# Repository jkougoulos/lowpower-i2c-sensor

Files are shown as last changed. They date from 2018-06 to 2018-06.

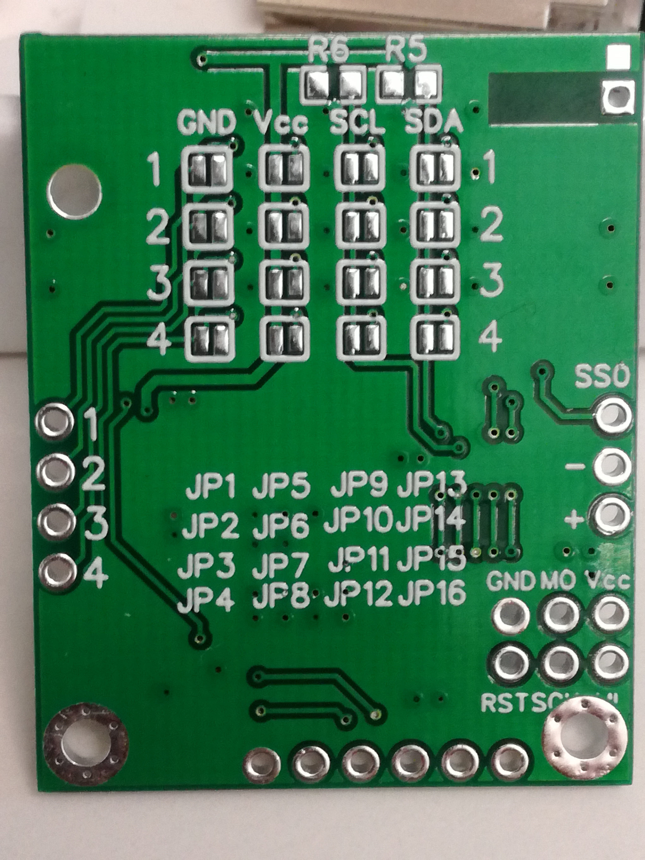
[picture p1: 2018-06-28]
Gerber_LowPowerI2CWirelessSensor-1.0-PCB/IMG_20180601_175646.jpg

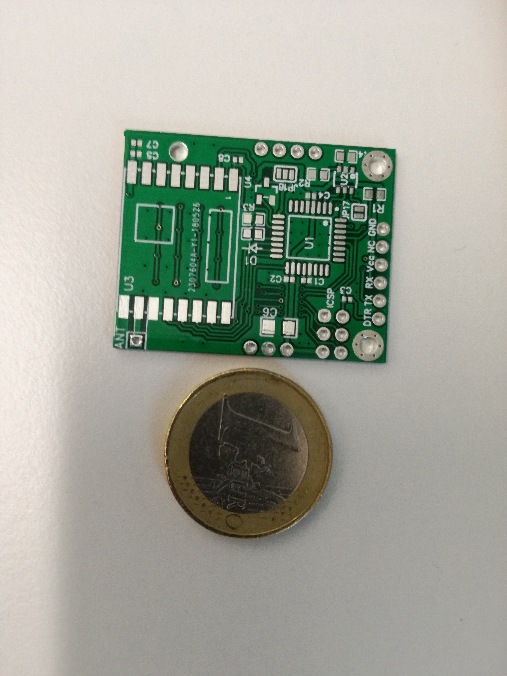
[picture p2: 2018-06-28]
Gerber_LowPowerI2CWirelessSensor-1.0-PCB/IMG_20180601_144345.jpg

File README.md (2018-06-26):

# lowpower-i2c-sensor
Another ATMega328PB based wireless sensor, designed for low power consumption

Currently testing and optimizing for 1Mhz operation, in order to be in Safe operating voltage without activating BOD (Vcc >= 1.8V). (4Mhz is not an option yet, no external oscillator forseen in design, so possible options are 1 or 8 Mhz)

using TPL5010 for low power consumption during sleep
Delay between wake-ups is governed by R2 & R4. Default { R2 = 29.4KOhm, R4 = not soldered } == 120.5-121 sec. 29.35KOhm is calculated for 2 min per datasheet (check it for possible values and combinations)

STM1061N for low battery voltage detection. 
Currently testing with 1.9v threshold (STM1061N19WX6F)
On the software side detection occurs using a pin CHANGE interrupt, in order to detect low voltage during the whole operation of the sensor (except sleep mode)

RFM69W for wireless communication, 45mA @ +13dBm. 

Jumper exists on the front side (JP18) for selecting power source for STM1061 (Vcc or PIN). Pin seems to work, next revision probably will not have the jumper.

JP19 enables the watchdog reset functionality of TPL5010. This will be probably removed in future version, since TPL5010 expects an initial pulse to be activated. However, if it is not activated, R2 seems to stay in measuring mode (further testing required), wasting battery capacity.

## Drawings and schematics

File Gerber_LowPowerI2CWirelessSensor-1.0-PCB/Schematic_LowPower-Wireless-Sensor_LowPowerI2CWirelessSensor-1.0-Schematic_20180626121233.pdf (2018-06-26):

# PE0(PTCXY/SDA1/ICP4/ACO) 3 VCC 4 GND 5

## VCC

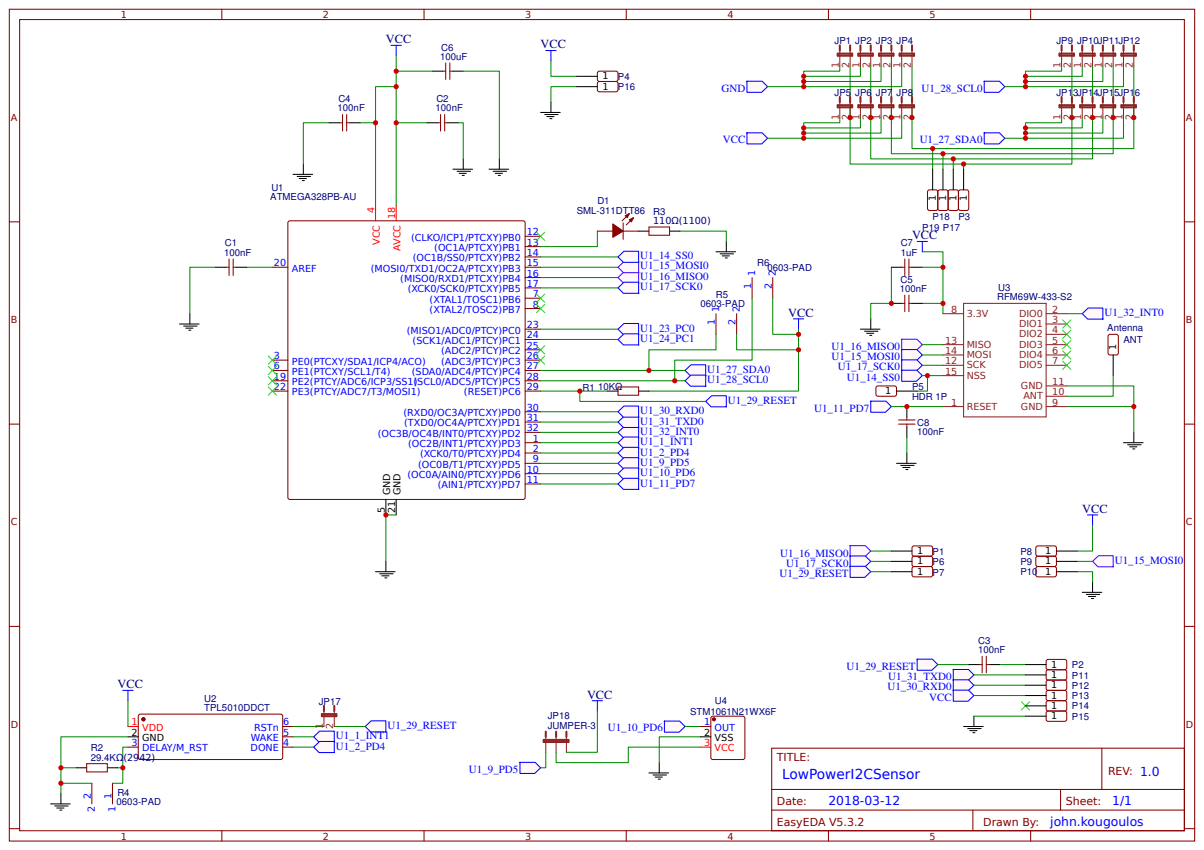
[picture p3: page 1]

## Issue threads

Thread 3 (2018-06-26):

Add extra pins for external devices

jkougoulos, 2018-06-26:
A few more pins would be nice to have, eg:
- something to receive interrupts / handle buttons
- have a pin to pulse and view the various phases in an oscilloscope

jkougoulos, 2018-06-26:
Don't forget to check requirements for PTC style buttons

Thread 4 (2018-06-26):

add a manual RESET switch - improve RESET mechanism

jkougoulos, 2018-06-26:
A switch for issuing RESET manually would be useful.
Need to check AVR042, but in general reset will probably get handled by TPL5010 manual reset options
Consider switching the RST pullup to 100KOhm, but need to check compaitibility with Serial upload (it should be ok), and ATMEL/Microchip debuggers.
Consider if bypass capacitor is required as per AVR042, ESD protection diodes, resistor. Normally these are not needed since ESD is actually something that would be handled by TPL5010 but detailed RTFM required.
Need to check if capacitor between DTR & RST for uploading over Serial (Arduino trick) interferes with ATMEL-ICE operation https://youtu.be/EsEl9wDz_Y8?t=1076

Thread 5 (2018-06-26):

Don't block while waiting for TX

jkougoulos, 2018-06-26:
As is, MCU will wait for the TX packet to be sent in order to continue operations. Perhaps do something else in the mean time (3-4ms)... but all calculation are already done :(

jkougoulos, 2018-06-27:
maybe go to sleep and wait for TX_done interrupt or low voltage to wake-up? but we need to make sure that we received TX_done to go further, so that in low-voltage we don't turn on the led while transmitting

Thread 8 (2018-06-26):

Consider alternatives for STM1061N

jkougoulos, 2018-06-26:
STM1061N might be difficult to find for specific voltages.
Consider alteratives. eg APX803L (Diodes incorporated), MCP111 (Microchip), check: https://www.digikey.de/products/en/integrated-circuits-ics/pmic-supervisors/691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

jkougoulos, 2021-07-08:
xc6135 super low power

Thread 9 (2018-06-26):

Self discharge of C6

jkougoulos, 2018-06-26:
Most of  battery power is consumed by self-discharge of C6 during idle time.
Need to measure somehow if the calculations are correct on the amount of battery capacity we lose and consider if the capacitor plays an important role on helping the battery for the high consuming pulse during TX. Perhaps using a 1-10uF X7R just for bypass would work better (and cost less)

jkougoulos, 2018-06-26:
See also:
https://www.embedded.com/electronics-blogs/break-points/4430050/Using-a-capacitor-to-sustain-battery-life

http://www.ti.com/lit/wp/swra349/swra349.pdf (Coin cells and peak current draw
By Mathias Jensen)

https://m.eet.com/media/1121454/c0924post.pdf

http://data.energizer.com/pdfs/lithiumcoin_appman.pdf

https://electronics.stackexchange.com/questions/43306/pulse-powering-heavy-loads-with-a-coin-cell

https://www.embedded.com/electronics-blogs/break-points/4429960/How-much-energy-can-you-really-get-from-a-coin-cell-

https://www.embedded.com/electronics-blogs/break-points/4418098/A-sneak-preview

jkougoulos, 2018-06-30:
testing required to see if large C6 actually helps. Actually it is 100uF but at 3v probably the usable is ~50uF. In any case, at 45mA of RFM69W full power, we need significantly bigger capacitor. The question though is if it helps mitigating the effects of increased IR of the battery (coin cell) at eg half life etc.
Test proposed:
fast cycles (8-16s) with 100uF (measure days until low bat & end of service)
fast cycles (8-16s) with 10uF
slower cycles (eg 64s) and check if the performance is linear, according to calculations.
Always start with same battery type, (cheap CR2032), similar environmental conditions (indoor).

at 14s delay, calculations predict at 180mAh ~448 days of operations. hmmm, that seems to long for a coin cell transmitting every 14s @45mA

jkougoulos, 2018-07-03:
http://cache.freescale.com/files/rf_if/doc/app_note/AN4573.pdf

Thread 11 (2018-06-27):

utilize hardware watchdog for unexpected bugs

jkougoulos, 2018-06-27:
We have to trigger watchdog intervention when something unexpected happens / fail (relatively) fast / heisenbugs etc
- packet was not sent
- temperature/humidity/pressure reading are out of the minimum/maximum
- make sure to send reset to RFM when starting up, ensuring that the module resets if something goes wrong

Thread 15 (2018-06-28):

Placeholder for various perfomance metrics

jkougoulos, 2018-06-28:
44-45ms runtime per cycle as of now:
Sequence:
- 13.5ms for taking measurement
- 13-14ms calculations/compensation & I2C retrieval (Adafruit library with enhancements for faster I2C)
- 5ms ? msg preparation (itoa/ltoa based, sprintf was ~10ms)
- 4-5 ms SPI I/O
- 4-5 ms wreless transmit
- 1ms LED on

Cheap multimeter measurements
- 640uA CPU when active (but idle / in delay()

Idle current cannot be measured by this cheap thing, getting 0uA (perhaps we are under 1uA)

Tested Bosch library (measure & calculate), without any optimization .
see: https://github.com/jkougoulos/BME280_driver/blob/master/BME280sensor.ino
Perhaps need to test using atmel studio, or disassembly.
- 30ms Float mode (strange result, need to check why float is faster!)
- ~39 ms int32/int64

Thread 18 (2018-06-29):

Provide visual feedback for low battery status

jkougoulos, 2018-06-29:

jkougoulos, 2018-06-29:
quick flashing 2 times is not visible without heavily delaying process time.

Perhaps in next hw version include a second led? What color though, so that it works with 2v?

Closed 2018-06-30.

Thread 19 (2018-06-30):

When TPL5010 is configured for small delays, cannot upload sketch over serial

jkougoulos, 2018-06-30:
noticed on test device 2, (tpl5010 configured with 29.4K // 22K -> 12583.66 Ohm) that the device resets frequently, making sketch upload impossible (at 9600bps).
Need to verify if TPL5010 issues reset (not expected)

jkougoulos, 2018-06-30:
perhaps disconnect JP19 to verify if TPL5010 brings RST low

jkougoulos, 2018-06-30:
could not reproduce

jkougoulos, 2018-07-16:
issue is still there, TPL5010 seems to send watchdog reset (not verified though) at 2x period. Perhaps during reset a pulse is given to done pin?

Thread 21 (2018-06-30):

Long term test 01 (TSTKO-0002)

jkougoulos, 2018-06-30:
Starting today 30.06.2018 long term test:
HW characteristics:
R2 // R4 == 29.4K // 22K
R1 = 100K (had done this to debug bootloader issues)

Battery επιπλάδικου:
CR2032 / 3.34v open voltage on multimeter

jkougoulos, 2018-07-05:
05.07.2018 watchdog reset followed by many reboots observed, then back to normal:
2018-07-05 15:35:52 2018-07-05 15:35:52 /dev/ttyUSB0 Received Frame is:bytearray(b'#SENSDATA#ID1:3e7/MS0:b180/C00:6ff3/T01:10a/H01:1c4/P01:275a/BAT:OK/RS0:-29')
2018-07-05 15:36:06 2018-07-05 15:36:06 /dev/ttyUSB0 Received Frame is:bytearray(b'#SENSDATA#ID1:3e7/MS0:b040/C00:6ff4/T01:10a/H01:1c6/P01:275b/BAT:OK/RS0:-33')
2018-07-05 15:36:21 2018-07-05 15:36:21 /dev/ttyUSB0 Received Frame is:bytearray(b'#SENSDATA#ID1:3e7/MS0:b100/C00:6ff5/T01:10a/H01:1c2/P01:275a/BAT:OK/RS0:-32')
2018-07-05 15:36:35 2018-07-05 15:36:35 /dev/ttyUSB0 Received Frame is:bytearray(b'#SENSDATA#ID1:3e7/MS0:b100/C00:6ff6/T01:10a/H01:1c3/P01:275a/BAT:OK/RS0:-33')
2018-07-05 15:36:50 2018-07-05 15:36:50 /dev/ttyUSB0 Received Frame is:bytearray(b'#SENSDATA#ID1:3e7/MS0:b040/C00:6ff7/T01:10a/H01:1c5/P01:275a/BAT:OK/RS0:-33')
2018-07-05 15:37:07 2018-07-05 15:37:07 /dev/ttyUSB0 Received Frame is:bytearray(b'#SENSDATA#ID1:3e7/MS0:1162c0/C00:1/T01:10a/H01:1c1/P01:275a/BAT:OK/RS0:-29')
2018-07-05 15:37:15 2018-07-05 15:37:15 /dev/ttyUSB0 Received Frame is:bytearray(b'#SENSDATA#ID1:3e7/MS0:1162c0/C00:1/T01:10a/H01:1c1/P01:2759/BAT:OK/RS0:-33')
2018-07-05 15:37:20 2018-07-05 15:37:20 /dev/ttyUSB0 Received Frame is:bytearray(b'#SENSDATA#ID1:3e7/MS0:1162c0/C00:1/T01:10a/H01:1c5/P01:275a/BAT:OK/RS0:-33')
2018-07-05 15:37:20 2018-07-05 15:37:20 /dev/ttyUSB0 Received Frame is:bytearray(b'#SENSDATA#ID1:3e7/MS0:ae00/C00:2/T01:10a/H01:1c5/P01:275a/BAT:OK/RS0:-33')
2018-07-05 15:37:28 2018-07-05 15:37:28 /dev/ttyUSB0 Received Frame is:bytearray(b'#SENSDATA#ID1:3e7/MS0:1162c0/C00:1/T01:10a/H01:1c6/P01:2759/BAT:OK/RS0:-29')
2018-07-05 15:37:33 2018-07-05 15:37:33 /dev/ttyUSB0 Received Frame is:bytearray(b'#SENSDATA#ID1:3e7/MS0:af00/C00:2/T01:10a/H01:1c7/P01:275a/BAT:OK/RS0:-33')
2018-07-05 15:37:40 2018-07-05 15:37:40 /dev/ttyUSB0 Received Frame is:bytearray(b'#SENSDATA#ID1:3e7/MS0:116280/C00:1/T01:10a/H01:1c5/P01:275a/BAT:OK/RS0:-33')
2018-07-05 15:37:46 2018-07-05 15:37:46 /dev/ttyUSB0 Received Frame is:bytearray(b'#SENSDATA#ID1:3e7/MS0:1162c0/C00:1/T01:10a/H01:1c4/P01:275a/BAT:OK/RS0:-33')
2018-07-05 15:37:48 2018-07-05 15:37:48 /dev/ttyUSB0 Received Frame is:bytearray(b'#SENSDATA#ID1:3e7/MS0:af00/C00:2/T01:10a/H01:1c5/P01:275a/BAT:OK/RS0:-33')
2018-07-05 15:38:05 2018-07-05 15:38:05 /dev/ttyUSB0 Received Frame is:bytearray(b'#SENSDATA#ID1:3e7/MS0:1164c0/C00:1/T01:10b/H01:1c4/P01:275a/BAT:OK/RS0:-29')
2018-07-05 15:38:17 2018-07-05 15:38:17 /dev/ttyUSB0 Received Frame is:bytearray(b'#SENSDATA#ID1:3e7/MS0:af00/C00:2/T01:10b/H01:1c6/P01:275a/BAT:OK/RS0:-32')
2018-07-05 15:38:31 2018-07-05 15:38:31 /dev/ttyUSB0 Received Frame is:bytearray(b'#SENSDATA#ID1:3e7/MS0:ab00/C00:3/T01:10a/H01:1c5/P01:275a/BAT:OK/RS0:-33')
2018-07-05 15:38:49 2018-07-05 15:38:49 /dev/ttyUSB0 Received Frame is:bytearray(b'#SENSDATA#ID1:3e7/MS0:116280/C00:1/T01:10a/H01:1c8/P01:275a/BAT:OK/RS0:-33')
2018-07-05 15:38:54 2018-07-05 15:38:54 /dev/ttyUSB0 Received Frame is:bytearray(b'#SENSDATA#ID1:3e7/MS0:1162c0/C00:1/T01:10a/H01:1c8/P01:275a/BAT:OK/RS0:-33')
2018-07-05 15:38:57 2018-07-05 15:38:57 /dev/ttyUSB0 Received Frame is:bytearray(b'#SENSDATA#ID1:3e7/MS0:116280/C00:1/T01:10b/H01:1c4/P01:275a/BAT:OK/RS0:-32')
2018-07-05 15:39:00 2018-07-05 15:39:00 /dev/ttyUSB0 Received Frame is:bytearray(b'#SENSDATA#ID1:3e7/MS0:aec0/C00:2/T01:10a/H01:1c4/P01:275a/BAT:OK/RS0:-33')
2018-07-05 15:39:15 2018-07-05 15:39:15 /dev/ttyUSB0 Received Frame is:bytearray(b'#SENSDATA#ID1:3e7/MS0:aa40/C00:3/T01:10a/H01:1c3/P01:275a/BAT:OK/RS0:-29')
2018-07-05 15:39:29 2018-07-05 15:39:29 /dev/ttyUSB0 Received Frame is:bytearray(b'#SENSDATA#ID1:3e7/MS0:ac00/C00:4/T01:10a/H01:1c4/P01:275a/BAT:OK/RS0:-33')
2018-07-05 15:39:44 2018-07-05 15:39:44 /dev/ttyUSB0 Received Frame is:bytearray(b'#SENSDATA#ID1:3e7/MS0:ab40/C00:5/T01:10a/H01:1c6/P01:275a/BAT:OK/RS0:-29')
2018-07-05 15:39:58 2018-07-05 15:39:58 /dev/ttyUSB0 Received Frame is:bytearray(b'#SENSDATA#ID1:3e7/MS0:aac0/C00:6/T01:10b/H01:1c2/P01:275a/BAT:OK/RS0:-33')
2018-07-05 15:40:13 2018-07-05 15:40:13 /dev/ttyUSB0 Received Frame is:bytearray(b'#SENSDATA#ID1:3e7/MS0:ab80/C00:7/T01:10b/H01:1c7/P01:275a/BAT:OK/RS0:-29')
2018-07-05 15:40:27 2018-07-05 15:40:27 /dev/ttyUSB0 Received Frame is:bytearray(b'#SENSDATA#ID1:3e7/MS0:ab00/C00:8/T01:10b/H01:1c4/P01:275a/BAT:OK/RS0:-33')
2018-07-05 15:40:42 2018-07-05 15:40:42 /dev/ttyUSB0 Received Frame is:bytearray(b'#SENSDATA#ID1:3e7/MS0:aac0/C00:9/T01:10b/H01:1c3/P01:275a/BAT:OK/RS0:-33')

3.04v on idle, ~400mV drop when transmitting IR = 9 Ohm... does not make a lot of sense, check http://data.energizer.com/pdfs/lithiumcoin_appman.pdf . perhaps we don't actually use 45mA (this is max for the transmitter, for other frequency). Behavior might show that there was a passivation layer which was eliminated today (after ~30000 cycles)

jkougoulos, 2018-07-11:
11.07.2018 ~37000 cycles after 05.07.2018
Vmax: 3.08 idle, 420mV drop, vupper 2.99v, vMin 2.66v

2018-07-11 20:29:08 2018-07-11 20:29:08 /dev/ttyUSB0 Received Frame is:bytearray(b'#SENSDATA#ID1:3e7/MS0:b0c0/C00:9059/T01:106/H01:1bd/P01:277c/BAT:OK/RS0:-31')
2018-07-11 20:29:23 2018-07-11 20:29:23 /dev/ttyUSB0 Received Frame is:bytearray(b'#SENSDATA#ID1:3e7/MS0:b0c0/C00:905a/T01:105/H01:1c1/P01:277c/BAT:OK/RS0:-32')
2018-07-11 20:29:37 2018-07-11 20:29:37 /dev/ttyUSB0 Received Frame is:bytearray(b'#SENSDATA#ID1:3e7/MS0:b140/C00:905b/T01:105/H01:1bd/P01:277c/BAT:OK/RS0:-32')
2018-07-11 20:29:52 2018-07-11 20:29:52 /dev/ttyUSB0 Received Frame is:bytearray(b'#SENSDATA#ID1:3e7/MS0:af40/C00:905c/T01:105/H01:1bc/P01:277d/BAT:OK/RS0:-32')

jkougoulos, 2018-07-12:
TSTKO-0001 showed similar reset behaviour, while powered from a CP2102:
2018-07-12 10:22:36 2018-07-12 10:22:36 /dev/ttyUSB1 Received Frame is:bytearray(b'#SENSDATA#ID1:3e6/MS0:ae80/C00:4c5/T01:f9/H01:1ed/P01:2790/BAT:OK/RS0:-42')
2018-07-12 10:24:37 2018-07-12 10:24:37 /dev/ttyUSB1 Received Frame is:bytearray(b'#SENSDATA#ID1:3e6/MS0:ae00/C00:4c6/T01:f9/H01:1ef/P01:2790/BAT:OK/RS0:-43')
2018-07-12 10:28:42 2018-07-12 10:28:42 /dev/ttyUSB1 Received Frame is:bytearray(b'#SENSDATA#ID1:3e6/MS0:116480/C00:1/T01:fb/H01:1ec/P01:2790/BAT:OK/RS0:-44')
2018-07-12 10:32:44 2018-07-12 10:32:44 /dev/ttyUSB1 Received Frame is:bytearray(b'#SENSDATA#ID1:3e6/MS0:151bc0/C00:1/T01:fc/H01:1e7/P01:2790/BAT:OK/RS0:-43')
2018-07-12 10:34:43 2018-07-12 10:34:43 /dev/ttyUSB1 Received Frame is:bytearray(b'#SENSDATA#ID1:3e6/MS0:ca100/C00:2/T01:fa6a/H01:0/P01:2abc/BAT:OK/RS0:-44')
2018-07-12 10:55:05 2018-07-12 10:55:05 /dev/ttyUSB1 Received Frame is:bytearray(b'#SENSDATA#ID1:3e6/MS0:ab66c0/C00:1/T01:fe/H01:1de/P01:2792/BAT:OK/RS0:-43')
2018-07-12 11:15:06 2018-07-12 11:15:06 /dev/ttyUSB1 Received Frame is:bytearray(b'#SENSDATA#ID1:3e6/MS0:12b740/C00:1/T01:ff/H01:1db/P01:2792/BAT:OK/RS0:-43')
2018-07-12 11:17:04 2018-07-12 11:17:04 /dev/ttyUSB1 Received Frame is:bytearray(b'#SENSDATA#ID1:3e6/MS0:15b80/C00:2/T01:ff/H01:1db/P01:2792/BAT:OK/RS0:-44')
2018-07-12 11:19:05 2018-07-12 11:19:05 /dev/ttyUSB1 Received Frame is:bytearray(b'#SENSDATA#ID1:3e6/MS0:13580/C00:3/T01:100/H01:1db/P01:2793/BAT:OK/RS0:-43')
2018-07-12 11:21:06 2018-07-12 11:21:06 /dev/ttyUSB1 Received Frame is:bytearray(b'#SENSDATA#ID1:3e6/MS0:f380/C00:4/T01:100/H01:1d8/P01:2792/BAT:OK/RS0:-44')

passivation is not the issue

jkougoulos, 2018-07-14:
possibly I2C freezing. Could be that the pullups for BME280 on this board should be replaced by direct connections as per datasheet

jkougoulos, 2018-07-16:
Device fails after fffe cycles, need to reset it

jkougoulos, 2018-07-16:
Modified code to not send pressure, also to wait for HW reset when packet was not sent. Hopefully the code to sleep while waiting was added - issue #19 appeared

jkougoulos, 2018-08-12:
12.08.2018 vmax 3.08 vupper 3.00 vmin 2.62 Vpp 440-460mV

jkougoulos, 2018-12-17:
Battery low messages appeared on 07.12.2018:
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
jkougoulos, 2018-12-17:
5.5 months of continuous operation

jkougoulos, 2019-01-14:
managed to measure battery (20190114) 2.92v open

jkougoulos, 2019-01-14:
20190114 Same hardware, starting now battery VARTA

jkougoulos, 2019-11-04:
hm, above mention is for TSTKO-0001, it ran out of battery:
2019-11-01 12:48:23 /dev/ttyUSB0 Received Frame is:bytearray(b'#SENSDATA#ID1:3e7/MS0:8e00/C00:165/T01:d5/H01:198/BAT:13/RS0:-33')
2019-11-01 12:48:38 /dev/ttyUSB0 Received Frame is:bytearray(b'#SENSDATA#ID1:3e7/MS0:8ec0/C00:166/T01:d5/H01:199/BAT:13/RS0:-33')

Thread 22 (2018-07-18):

Long term test 2 (TSTKO-0001)

jkougoulos, 2018-07-18:
Due to DHT22-0003 does not have antenna any more, TSTKO-0001, full power with a new VARTA 2032 has been deployed in external area

jkougoulos, 2018-10-09:
Last measurement:
2018-10-08 13:09:52 /dev/ttyUSB3 Received Frame is:bytearray(b'#SENSDATA#ID1:3e6/MS0:8f80/C00:29c2/T01:8e/H01:24d/BAT:OK/RS0:-56')

need to check status.

Also logs show the following:

2018-10-08 11:51:22 /dev/ttyUSB3 Received Frame is:bytearray(b'#SENSDATA#ID1:3e6/MS0:8d40/C00:299b/T01:78/H01:2cf/BAT:13/RS0:-55')
2018-09-23 13:21:54 /dev/ttyUSB3 Received Frame is:bytearray(b'#SENSDATA#ID1:3e6/MS0:8cc0/C00:1124/T01:90/H01:34b/BAT:13/RS0:-62')
2018-09-23 13:01:46 /dev/ttyUSB3 Received Frame is:bytearray(b'#SENSDATA#ID1:3e6/MS0:8dc0/C00:111a/T01:97/H01:32f/BAT:13/RS0:-60')
2018-09-16 08:16:09 /dev/ttyUSB3 Received Frame is:bytearray(b'#SENSDATA#ID1:3e6/MS0:8dc0/C00:1b5f/T01:7a/H01:2e6/BAT:13/RS0:-57')

jkougoulos, 2018-10-10:
New VARTA was installed, let's repeat the test. Possible issues could be the strange battery holder

jkougoulos, 2018-11-18:
lasted until 04.11.2018 ... this happened:
2018-11-04 02:25:40 /dev/ttyUSB5 Received Frame is:bytearray(b'#SENSDATA#ID1:3e6/MS0:8ec0/C00:4541/T01:22/H01:33f/BAT:OK/RS0:-73')
2018-11-04 02:27:41 /dev/ttyUSB5 Received Frame is:bytearray(b'#SENSDATA#ID1:3e6/MS0:8ec0/C00:4542/T01:22/H01:33b/BAT:OK/RS0:-72')
2018-11-04 02:29:41 /dev/ttyUSB5 Received Frame is:bytearray(b'#SENSDATA#ID1:3e6/MS0:8f00/C00:4543/T01:23/H01:33e/BAT:OK/RS0:-75')
2018-11-04 02:29:43 /dev/ttyUSB5 Received Frame is:bytearray(b'#SENSDATA#ID1:3e6/MS0:114840/C00:1/T01:23/H01:33f/BAT:OK/RS0:-76')
2018-11-04 02:31:42 /dev/ttyUSB5 Received Frame is:bytearray(b'#SENSDATA#ID1:3e6/MS0:8d80/C00:2/T01:23/H01:33c/BAT:OK/RS0:-76')

followed by this:

2018-11-04 11:31:12 /dev/ttyUSB5 Received Frame is:bytearray(b'#SENSDATA#ID1:3e6/MS0:8d80/C00:10e/T01:62/H01:328/BAT:OK/RS0:-72')
2018-11-04 11:33:13 /dev/ttyUSB5 Received Frame is:bytearray(b'#SENSDATA#ID1:3e6/MS0:8c80/C00:10f/T01:63/H01:327/BAT:OK/RS0:-74')
2018-11-04 11:37:14 /dev/ttyUSB5 Received Frame is:bytearray(b'#SENSDATA#ID1:3e6/MS0:8b80/C00:111/T01:63/H01:328/BAT:OK/RS0:-74')
2018-11-04 11:39:15 /dev/ttyUSB5 Received Frame is:bytearray(b'#SENSDATA#ID1:3e6/MS0:8c80/C00:112/T01:64/H01:327/BAT:OK/RS0:-73')
2018-11-04 11:41:16 /dev/ttyUSB5 Received Frame is:bytearray(b'#SENSDATA#ID1:3e6/MS0:8dc0/C00:113/T01:64/H01:322/BAT:OK/RS0:-81')
2018-11-05 05:31:26 /dev/ttyUSB5 Received Frame is:bytearray(b'#SENSDATA#ID1:3e6/MS0:114840/R(\xdb%\xf8T\xaa\x96\x97\x92\x15\x96yP|\x8d\x866m\xc3\xbeo"\x94\xeb\x05\xf1/RS0:-106')

then stuck on rebooting every 10-12 secs, possibly IR was too large while transmitting, causing reset

Need to check also with different batttery holder, different hw and different battery. Not really sure if the root cause is one of those, or the weather conditions. TSTKO-002 runs many months without issues so far, but inside, different battery, different battery holder, different hw obviously

jkougoulos, 2022-01-18:
do not remember a lot. Indoor test lasted ~3 years

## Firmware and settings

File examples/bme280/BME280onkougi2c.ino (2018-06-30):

#include <avr/wdt.h>
#include <avr/sleep.h>
#include <avr/power.h>
#include <avr/boot.h>


#include <Wire.h>
#include <utility/twi.h>

#include <Adafruit_BME280.h>

#include <RH_RF69.h>
#define MYMTU 60
#define MYTTL 8
RH_RF69 driver;



#define NUM_8S_SLEEP 1

//#define DEBUGSENSOR
//#define DEBUGSENSORTIMING


#define TPL5010_WAKE_PIN 3
#define TPL5010_DONE_PIN 4
#define STM1061_POWER 5
#define STM1061_OUTPUT 6
#define LED 9

int myID = 999;
char data[255];
byte pos = 0;

unsigned long Cycle = 0;
unsigned long CycleT = 0;
uint16_t msgseq = 0;

Adafruit_BME280 bme;
#define SEALEVELPRESSURE_HPA (1013.25)
#define BME280_I2CADDR 0x76
bool bme_status;

volatile int lowvolt_initial ;
volatile int lowvolt_phase ;
volatile bool lowvolt_send_pend = false;
volatile int phase ;

void checkRFINIT()
{
  if (!driver.init())
  {
#ifdef DEBUGSENSOR
    Serial.println("Driver init failed");
#endif    
  }
  if ( !driver.setFrequency(433.0) )
  {
#ifdef DEBUGSENSOR    
    Serial.println("Radio setFrequency failed");
#endif    
  }
  else
  {
#ifdef DEBUGSENSOR    
    Serial.println("RFM69W init ok!");
#endif    
  }
  driver.sleep();
  return;
}

void configure_wdt(void)
{
   
    cli();                           // disable interrupts for changing the registers
  
    MCUSR = 0;                       // reset status register flags
  
                                     // Put timer in interrupt-only mode:                                       
    WDTCSR |= 0b00011000;            // Set WDCE (5th from left) and WDE (4th from left) to enter config mode,
                                     // using bitwise OR assignment (leaves other bits unchanged).
//    WDTCSR =  0b01000000 | 0b000110; // 1 sec
//    WDTCSR =  0b01000000 | 0b000111; // 2 sec

    WDTCSR =  0b01000000 | 0b100001; // set WDIE: interrupt enabled
                                     // clr WDE: reset disabled
                                     // and set delay interval (right side of bar) to 8 seconds
    sei();                           // re-enable interrupts 
}

void tpl5010_wake( void )
{
   detachInterrupt(digitalPinToInterrupt(TPL5010_WAKE_PIN));
}

void send_tpl5010_done()
{  
  digitalWrite(TPL5010_DONE_PIN,HIGH);
  delayMicroseconds(1);
  digitalWrite(TPL5010_DONE_PIN,LOW);
  
  return;
}


ISR(PCINT2_vect)
{

   int stm1061_current = digitalRead( STM1061_OUTPUT );
   if ( stm1061_current == LOW )
   {
      lowvolt_send_pend = true;
      lowvolt_phase = phase;
      pciClear( STM1061_OUTPUT );
      digitalWrite( STM1061_POWER, LOW ); // turn off voltage detection to prevent flapping and lower power usage
   }
   else
   {
      lowvolt_phase = 99;
   }
}
  
ISR(WDT_vect)
{
  
     if( 1 )
     {
        wdt_reset();
     }
     else
     {
        // must be rebooted
        // configure
        MCUSR = 0;                          // reset flags
         
                                              // Put timer in reset-only mode:
        WDTCSR |= 0b00011000;               // Enter config mode.
        WDTCSR =  0b00001000 | 0b000000;    // clr WDIE (interrupt enable...7th from left)
                                              // set WDE (reset enable...4th from left), and set delay interval
                                              // reset system in 16 ms...
                                              // unless wdt_disable() in loop() is reached first
                                         
        // reboot
        while(1);
     }
}


void sleepNow(int num8s = 1)         // here we put the arduino to sleep
{
    for( int i = 0 ; i < num8s ; i++ )
    {
        set_sleep_mode(SLEEP_MODE_PWR_DOWN);   // sleep mode is set here
        cli();

        attachInterrupt( digitalPinToInterrupt(TPL5010_WAKE_PIN), tpl5010_wake , RISING );

        sleep_enable();
        sleep_bod_disable();
        sei();
        sleep_cpu();
        sleep_disable();
        sei();
    }

}


void WDT_off(void)
{
  cli(); // __disable_interrupt();
  wdt_reset(); //__watchdog_reset();
  /* Clear WDRF in MCUSR */
  MCUSR &= ~(1<<WDRF);
  /* Write logical one to WDCE and WDE */
  /* Keep old prescaler setting to prevent unintentional
  time-out */
  WDTCSR |= (1<<WDCE) | (1<<WDE);
  /* Turn off WDT */
  WDTCSR = 0x00;
  sei(); //__enable_interrupt();
}

  
// the setup routine runs once when you press reset:
void setup() {

  int oldMCUSR = MCUSR;
  
  MCUSR = 0;
  // initialize serial communication at 9600 bits per second:
#if defined(DEBUGSENSOR) || defined(DEBUGSENSORTIMING)
  Serial.begin(9600);
  
  Serial.print("Hallo! MCUSR was:");
  Serial.println( oldMCUSR );


    cli();
    uint8_t lowBits      = boot_lock_fuse_bits_get(GET_LOW_FUSE_BITS);
    uint8_t highBits     = boot_lock_fuse_bits_get(GET_HIGH_FUSE_BITS);
    uint8_t extendedBits = boot_lock_fuse_bits_get(GET_EXTENDED_FUSE_BITS);
    uint8_t lockBits     = boot_lock_fuse_bits_get(GET_LOCK_BITS);
    sei();

    Serial.print("Fuses: ");
    Serial.print("Low: 0x");
    Serial.print(lowBits, HEX);
    Serial.print(" High: 0x");
    Serial.print(highBits, HEX);
    Serial.print(" Ext: 0x");
    Serial.print(extendedBits, HEX);
    Serial.print(" Lock: 0x");
    Serial.println(lockBits, HEX);

    char tmpstr[3];
    Serial.print("Signature: 0x");
    for (uint8_t i = 0; i < 5; i += 2) {
//        Serial.print("i:") ; Serial.print(i); Serial.print(" ");
        
//        Serial.println(boot_signature_byte_get(i), HEX);
        sprintf(tmpstr,"%02X",boot_signature_byte_get(i));
        Serial.print(tmpstr);
    }
    Serial.println();

    
    Serial.print("Serial Number: 0x");
    for (uint8_t i = 14; i < 24; i += 1) {
//        Serial.print(" 0x");
//        Serial.print(i); Serial.print(":");
        sprintf(tmpstr,"%02X",boot_signature_byte_get(i));
//        Serial.println(boot_signature_byte_get(i), HEX);
        Serial.print(tmpstr);
    }
    Serial.println();
#endif  
 
  WDT_off();

#ifdef DEBUGSENSOR
  configure_wdt();
#endif


  DDRB =  0b00000010 ; // 0x00;        //make port a as input except pin 9 / B1 / LED
  PORTB = 0b11111101 ; // 0xFF;       // with pullup

  DDRC = 0x7F;        // make port C as input
  PORTC = 0x7F;       // with pullup

  DDRD =  0b00110000; //0x00;        // make port D as input except PD4 / TPL5010 DONE
  PORTD = 0b01000111; // 0xFF;       // with pullup except PD3 / 3 / TPL5010 WAKE / 5,6 STM / 7 RFM-RST

  DDRE = 0x00;        //make port a as input
  PORTE = 0xF;       // with pullup (4 bit port)

  ADCSRA = 0;  // need to shutdown ADC before disabling
  
  PRR1 = (1 << PRTWI1) | (1 << PRTIM4) | (1 << PRSPI1) | (1 << PRPTC) | (1 << PRTIM3);
//  PRR0 = (1 << PRTIM2) | (1 << PRTIM0) | (1 << PRTIM1) | (1 << PRTWI0) | (1 << PRUSART1) | (1 << PRUSART0) | (1 << PRADC) | (1 << PRSPI0);
  PRR0 =  (1 << PRTIM2)  | (1 << PRTIM1) | (1 << PRUSART1) | (1 << PRADC)    // we need timer0 for delay()/micros() etc. SPI0 for RFM, TWI0 for sensor
#if !defined(DEBUGSENSOR) && !defined(DEBUGSENSORTIMING)
          | (1 << PRUSART0 )    // shutdown serial when not debugging
#endif
          ;          

   pinMode(LED, OUTPUT);
   digitalWrite(LED,LOW);
   
   pinMode(TPL5010_WAKE_PIN, INPUT);
   pinMode(TPL5010_DONE_PIN, OUTPUT);
   send_tpl5010_done(); // startup TPL5010; otherwise resistor for setting delay consumes power 
   
   pinMode(STM1061_POWER,OUTPUT);
   digitalWrite(STM1061_POWER, LOW);
   pinMode(STM1061_OUTPUT,INPUT_PULLUP);

    
    // default settings
    // (you can also pass in a Wire library object like &Wire2)
   bme_status = bme.begin( BME280_I2CADDR );  
   if (!bme_status) {
#if defined(DEBUSENSOR) || defined(DEBUGSENSORTIMING)    
       Serial.println("Could not find a valid BME280 sensor, check wiring!");
#endif
       while (1);  // wait for watchdog to reset us
   }

/* twi bit rate formula from atmega128 manual pg 204
  SCL Frequency = CPU Clock Frequency / (16 + (2 * TWBR))
  note: TWBR should be 10 or higher for master mode
  It is 72 for a 16mhz Wiring board with 100kHz TWI */
#if F_CPU == 1000000        //koug
   TWBR = 0;  // get MAX speed on I2C bus (62.5Khz in 1Mhz CPU)
#endif

   checkRFINIT();
  
   
}

void transmitInfo()
{
  int data_size = strlen(data);

  if( driver.send( (uint8_t *)data, data_size ) )
  {
      //sleepNow(1);   // power down cpu while transmitting 
      driver.waitPacketSent();
#ifdef DEBUGSENSOR
      Serial.println( "###\nData sent!");
      delay(200);
#endif
  }
#ifdef DEBUGSENSOR
  else
  {
      Serial.println( "###\nData NOT sent!");
      delay(100);
  }
#endif
  return;  
}



void pciSetup(byte pin)
{
    *digitalPinToPCMSK(pin) |= bit (digitalPinToPCMSKbit(pin));  // enable pin
    PCIFR  |= bit (digitalPinToPCICRbit(pin)); // clear any outstanding interrupt
    PCICR  |= bit (digitalPinToPCICRbit(pin)); // enable interrupt for the group
}

void pciClear(byte pin)
{
    *digitalPinToPCMSK(pin) &= ~(bit (digitalPinToPCMSKbit(pin)));  // disable pin
    PCIFR  |= bit (digitalPinToPCICRbit(pin)); // clear any outstanding interrupt
    PCICR  &= ~(bit (digitalPinToPCICRbit(pin))); // disable interrupt for the group
}

void lowvolt_detect_activate()
{
  
  digitalWrite(STM1061_POWER, HIGH);
  delayMicroseconds(200);  // wait for STM to stabilize

  lowvolt_initial = digitalRead( STM1061_OUTPUT ) ;
  if( lowvolt_initial == LOW ) // low voltage detected
  {
#ifdef DEBUGSENSOR
    Serial.print("STML ");
#endif    
    lowvolt_send_pend = true;
  }
  else         // HIGH therefore voltage now is ok, attaching interrupt to monitor changes
  {
#ifdef DEBUGSENSOR
    Serial.print("STMH ");
#endif    
    pciSetup( STM1061_OUTPUT );
  }
 }

void add_tag_to_data(const char *tag,byte taglen, void *val,bool islong)
{
    
    
    strcpy( data+pos, tag );
    pos += taglen;
    
    if( islong )
    {
      ltoa( *(long *)val, data+pos,16);
    }
    else
    {
      itoa( *(int*)val, data+pos,16);
    }
    pos = pos + strlen(data+pos);

    return;
}




// the loop routine runs over and over again forever:
void loop() {


  phase = 0;

#ifdef DEBUGSENSORTIMING  
  unsigned long t0 = micros();
#endif
  
  
  Cycle++;

 //  if( Cycle == 3 )  { while(1) {}; }        // test watchdog reset
  
  
  phase = 1;
  
  if( !lowvolt_send_pend )
  {
    lowvolt_detect_activate();
  }
 
  phase = 10;
#ifdef DEBUGSENSORTIMING
  unsigned long t10  = micros() - t0;
  unsigned long t14 = 0;
  unsigned long t15 = 0;
  unsigned long t16 = 0;
  unsigned long t17 = 0;
#endif


 // int but multiplied by 10 to keep the first decimal digit
  int temp_int = 0;
  int hum_int = 0;
  int pressure_int = 0 ;
  
  if( bme_status )  
  {
    bme.takeForcedMeasurement();

#ifdef DEBUGSENSORTIMING
    phase = 14;
    t14  = micros() - t0;
#endif


//    bme.readPTHFast( &pressure, &temp, &hum );
   bme.readPTHFast( &pressure_int, &temp_int, &hum_int );
}
  
  phase = 18;
#ifdef DEBUGSENSORTIMING
  unsigned long t18  = micros() - t0;
#endif


  unsigned long currmicros = micros();
  CycleT = currmicros - CycleT;
  
 
    pos = 0;

//    sprintf(data,"<ID0:%d/MS0:%ld/C00:%ld/T01:%d/H01:%d/P01:%d>\n",myID,millis(),Cycle,temp_int,hum_int,pressure_int);
//    sprintf(data,"<ID0:%d/MS0:%ld/C00:%ld/T01:%d/H01:%d/P01:%d>\n",myID,CycleT,Cycle,temp_int,hum_int,pressure_int);

    data[pos++] = '<';

    add_tag_to_data("ID1:", 4, &myID, false);
    add_tag_to_data("/MS0:", 5, &CycleT, true);
    add_tag_to_data("/C00:", 5, &Cycle, true);
    add_tag_to_data("/T01:", 5, &temp_int, false);
    add_tag_to_data("/H01:", 5, &hum_int, false);
    add_tag_to_data("/P01:", 5, &pressure_int, false);

 

  if( lowvolt_send_pend )
  {
    add_tag_to_data("/BAT:", 5, &lowvolt_phase, false);

//    sprintf(data,"<ID0:%d/MS0:%ld/C00:%ld/T01:%d/H01:%d/P01:%d/BAT:L%d>\n",myID,CycleT,Cycle,temp_int,hum_int,pressure_int,lowvolt_phase);
    lowvolt_send_pend = false;
    lowvolt_phase = 0;
    lowvolt_detect_activate();
  }
  else
  {
    data[pos++] = '/';
    data[pos++] = 'B';
    data[pos++] = 'A';
    data[pos++] = 'T';
    data[pos++] = ':';
    data[pos++] = 'O';
    data[pos++] = 'K';
  }

  data[pos++] = '>';
  data[pos++] = '\n';
  data[pos++] = '\0';

//    Serial.println(data);

  
  CycleT = currmicros;

  phase = 19;

#ifdef DEBUGSENSORTIMING
  unsigned long t19  = micros() - t0;
#endif
  
  transmitInfo();
  driver.sleep();

  phase = 20;

#ifdef DEBUGSENSORTIMING
  unsigned long t20  = micros() - t0;
#endif

  digitalWrite(LED, HIGH);
  delayMicroseconds(1000);
  digitalWrite(LED, LOW);

  phase = 25;
#ifdef DEBUGSENSORTIMING
  unsigned long t25  = micros() - t0;
#endif

  phase = 30;
#ifdef DEBUGSENSORTIMING
  unsigned long t30  = micros() - t0;
#endif
  
  send_tpl5010_done();

  phase = 40;
#ifdef DEBUGSENSORTIMING
  unsigned long t40  = micros() - t0;
#endif

  pciClear( STM1061_OUTPUT );
  digitalWrite(STM1061_POWER, LOW);

#ifdef DEBUGSENSORTIMING
  Serial.print("t0: ");
  Serial.println(t0);
  Serial.print("t10: ");
  Serial.println(t10);
  Serial.print("t14: ");
  Serial.println(t14);
  Serial.print("t15: ");
  Serial.println(t15);
  Serial.print("t16: ");
  Serial.println(t16);
  Serial.print("t17: ");
  Serial.println(t17);
  Serial.print("t18: ");
  Serial.println(t18);
  Serial.print("t19: ");
  Serial.println(t19);
  Serial.print("t20: ");
  Serial.println(t20);
  Serial.print("t25: ");
  Serial.println(t25);
  Serial.print("t30: ");
  Serial.println(t30);
  Serial.print("t40: ");
  Serial.println(t40);
 /*
  Serial.print( "BAT LOW @ " );
  Serial.println( lowvolt_phase );
  Serial.println(temp_int);
  Serial.println(hum_int);
  Serial.println(pressure_int);
  */
  Serial.println("<---------->");

  delay(100);
#endif

  //delay(5000);
  sleepNow(NUM_8S_SLEEP);
 
}
